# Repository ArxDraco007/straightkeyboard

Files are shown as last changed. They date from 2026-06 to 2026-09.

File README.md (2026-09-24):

# ArxKeyboard - A Custom Keyboard
## Building a custom mechanical keyboard from scratch.

## Why did I make this project?
Keyboards are a crucial part and parcel of your everyday life and efficiency, and it is crucial for you to have the very best.
It is also a very fun project to make, and it is also very cool to have your own custom keyboard.

## Description
This keyboard is a full-size mechanical keyboard. This has a custom PCB built around an ESP32-S3 WROOM. It contains a 6x17 switch matrix. It is a  two-piece case, red top shell over a blue base, designed in Fusion 360 and printed to match hole-for-hole with the PCB mounting points. It is running KMK on the firmware side.

## Pictures - 
The Schematic


The PCB


The CAD Model
keeb

## Zine
zine (7)

# Bill of Materials (BOM)

| Ref. | Value / Part Number | Footprint | Qty. | Supplier | Link | Notes |
|:---|:---|:---|---:|:---|:---|:---|
| C1 | 100 nF | 0603 | 1 | Robu.in | [100 nF 0603 — Pack of 40](https://robu.in/product/100nf-0603-surface-mount-multilayer-ceramic-capacitor-pack-of-40) | X7R, 50 V |
| C2 | 22 nF | 0603 | 1 | Robu.in | [22 nF 0603 — Pack of 50](https://robu.in/product/22nf-0603-surface-mount-multilayer-ceramic-capacitor-pack-of-50/) | 0603 MLCC |
| C11 | 10 µF | EIA-3216-18 (Case A) | 1 | Robu.in | [Vishay 10 µF 16 V Tantalum](https://robu.in/product/293d106x0016a2te3-vishay-tantalum-capacitor-10uf-16v-3-ohm-0-2-3216-18) | Vishay, 10 µF, 16 V; check stock |
| C12 | 22 µF | EIA-3216-18 (Case A) | 1 | element14 India | [22 µF 3216 Tantalum](https://in.element14.com/search?st=22uF+3216+tantalum) | Source from element14 India |
| R1 | 5.1 kΩ | 0603 | 1 | Robu.in | [YAGEO RC0603JR-075K1L](https://robu.in/product/rc0603jr-075k1l-yageo-res-thick-film-0603-5-1k-ohm-5-0-1w1-10w-%C2%B1100ppm-c-pad-smd-t-r/) | USB-C CC pull-down |
| R2 | 5.1 kΩ | 0603 | 1 | Robu.in | [YAGEO RC0603JR-075K1L](https://robu.in/product/rc0603jr-075k1l-yageo-res-thick-film-0603-5-1k-ohm-5-0-1w1-10w-%C2%B1100ppm-c-pad-smd-t-r/) | USB-C CC pull-down |
| R4 | 10 kΩ | 0603 | 1 | Robu.in | [10 kΩ 0603 SMD — Pack of 100](https://robu.in/product/10k-ohm-1-4w-0603-surface-mount-chip-resistor-pack-of-100/) | 1/4 W SMD resistor |
| D1–D88 | 1N4148W-7-F | SOD-123 | 88 | Evelta.com | [1N4148W-7-F — Diodes Inc.](https://evelta.com/1n4148w-7-f-100v-300ma-fast-switching-diode-2pin-smt-sod123/) | 100 V, 300 mA; genuine Diodes Inc. |
| U1 | ESP32-S3-WROOM-1-N16R8 | Module | 1 | Robu.in | [ESP32-S3-WROOM-1-N16R8](https://robu.in/product/espressif-esp32-s3-wroom-1-n16r8-module/) | 16 MB Flash, 8 MB PSRAM |
| U2 | AMS1117-3.3 | SOT-223 | 1 | Evelta.com | [AMS1117-3.3](https://evelta.com/ams1117-3-3-advanced-monolithic-systems-3-3v-1a-ldo-voltage-regulator/) | 3.3 V, 1 A LDO |
| J1 | GCT USB4105-GF-A-060 | 16P Top-Mount SMD | 1 | element14 India | [USB4105-GF-A-060](https://in.element14.com/gct-global-connector-technology/usb4105-gf-a-060/usb-conn-2-0-type-c-r-a-rcpt-16pos/dp/3777659) | USB-C, 16-pin, top-mount SMD |
| SW1–SW88 | Cherry MX2A | PCB Mount | 88 | Meckeys.com | [Cherry MX2A — 10 Pack](https://meckeys.com/shop/accessories/keyboard-accessories/key-switches/cherry-mx2a-switch/) | ₹350 / 10-pack; ≈ ₹3,080 total |
| PCB | ArxKey, 2-Layer, 280 × 130 mm | — | 5 | JLCPCB | [JLCPCB](https://jlcpcb.com/) | Manufacturing cost: $7 |

---

## Cost Summary

| Item | Estimated Cost |
|:---|---:|
| Components | Included above |
| Cherry MX2A switches | ≈ ₹3,080 |
| PCB manufacturing — 5 boards | $7 |
| **Estimated Total** | **≈ $57** |

## Stuff You Need to Remember When Making This!!! - 
- The Case is of 5 parts, you just have to place them right and screw them properly.
- Make sure U1 is in the keepout zone.
- Flash the ESP32 before assembly for testing.
- Don't reverse Tantalum capacitors, they pop (Electroboom reference(if you get it)).
- One SOD-123 per key in the matrix facing right.
- Mount in mounting holes!
- Look at the zine and sandwich the PCB.
- Do everything right or else you're cooked.

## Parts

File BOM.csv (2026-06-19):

Ref | Value | Footprint | Qty | Supplier | Link | Notes
C1 | 100nF | 0603 | 1 | Robu.in | https://robu.in/product/100nf-0603-surface-mount-multilayer-ceramic-capacitor-pack-of-40 | X7R 50V
C2 | 22nF | 0603 | 1 | Robu.in | https://robu.in/product/22nf-0603-surface-mount-multilayer-ceramic-capacitor-pack-of-50/ | 0603 MLCC
C11 | 10uF | EIA-3216-18 (Case A) | 1 | Robu.in | https://robu.in/product/293d106x0016a2te3-vishay-tantalum-capacitor-10uf-16v-3-ohm-0-2-3216-18 | Vishay 10uF 16V Tantalum; check stock
C12 | 22uF | EIA-3216-18 (Case A) | 1 | element14 India | https://in.element14.com/search?st=22uF+3216+tantalum | No confirmed listing on Robu/Evelta; source from element14 India
R1 | 5.1kΩ | 0603 | 1 | Robu.in | https://robu.in/product/rc0603jr-075k1l-yageo-res-thick-film-0603-5-1k-ohm-5-0-1w1-10w-%C2%B1100ppm-c-pad-smd-t-r/ | USB-C CC pull-down; YAGEO RC0603JR-075K1L
R2 | 5.1kΩ | 0603 | 1 | Robu.in | https://robu.in/product/rc0603jr-075k1l-yageo-res-thick-film-0603-5-1k-ohm-5-0-1w1-10w-%C2%B1100ppm-c-pad-smd-t-r/ | USB-C CC pull-down; YAGEO RC0603JR-075K1L
R4 | 10kΩ | 0603 | 1 | Robu.in | https://robu.in/product/10k-ohm-1-4w-0603-surface-mount-chip-resistor-pack-of-100/ | 10k 1/4W 0603 SMD
D1-D88 | 1N4148W-7-F | SOD-123 | 88 | Evelta.com | https://evelta.com/1n4148w-7-f-100v-300ma-fast-switching-diode-2pin-smt-sod123/ | Diodes Inc; 100V 300mA; genuine
U1 | ESP32-S3-WROOM-1-N16R8 | Module | 1 | Robu.in | https://robu.in/product/espressif-esp32-s3-wroom-1-n16r8-module/ | 16MB Flash 8MB PSRAM
U2 | AMS1117-3.3 | SOT-223 | 1 | Evelta.com | https://evelta.com/ams1117-3-3-advanced-monolithic-systems-3-3v-1a-ldo-voltage-regulator/ | AMS original; 1A LDO; ~₹12
J1 | GCT USB4105-GF-A | 16P Top Mount SMD | 1 | element14 India | https://in.element14.com/gct-global-connector-technology/usb4105-gf-a-060/usb-conn-2-0-type-c-r-a-rcpt-16pos/dp/3777659 | USB-C 16P top mount SMD
SW1-SW88 | Cherry MX2A | PCB Mount | 88 | Meckeys.com | https://meckeys.com/shop/accessories/keyboard-accessories/key-switches/cherry-mx2a-switch/ | ₹3080 total
PCB | ArxKey 2-layer | 280x130mm | qty 5*1 | JLCPCB | jlcpcb.com | $7 Manufacturing PCB
Total |  |  |  |  |  | $57

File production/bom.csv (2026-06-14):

Designator | Footprint | Quantity | Value | LCSC Part #
C1 | 0603 | 1 | 100nF
C11 | CP_EIA-3216-18_Kemet-A | 1 | 10uF
C12 | CP_EIA-3216-18_Kemet-A | 1 | 22uF
C2 | 0603 | 1 | 22nF
D1, D10, D11, D12, D13, D14, D15, D16, D17, D18, D19, D2, D20, D21, D22, D23, D24, D25, D26, D27, D28, D29, D3, D30, D31, D32, D33, D34, D35, D36, D37, D38, D39, D4, D40, D41, D42, D43, D44, D45, D46, D47, D48, D49, D5, D50, D51, D52, D53, D54, D55, D56, D57, D58, D59, D6, D60, D61, D62, D63, D64, D65, D66, D67, D68, D69, D7, D70, D71, D72, D73, D74, D75, D76, D77, D78, D79, D8, D80, D81, D82, D83, D84, D85, D86, D87, D88, D9 | D_SOD-123 | 88 | ~
J1 | USB_C_Receptacle_GCT_USB4105-xx-A_16P_TopMnt_Horizontal | 1 | USB_C_Receptacle_USB2.0_16P
R1, R2 | 0603 | 2 | 5.1k
R4 | 0603 | 1 | 10k
S1, S10, S11, S12, S13, S14, S15, S16, S17, S18, S19, S2, S20, S21, S22, S23, S24, S25, S26, S27, S28, S29, S3, S31, S32, S33, S35, S36, S37, S38, S39, S4, S40, S41, S42, S43, S44, S45, S46, S48, S49, S5, S50, S52, S53, S54, S55, S56, S57, S58, S59, S6, S60, S61, S62, S63, S65, S66, S67, S68, S69, S7, S70, S71, S72, S73, S74, S75, S77, S79, S8, S80, S82, S83, S84, S86, S87, S88, S9 | SW_Cherry_MX_1.00u_PCB | 79 | ~
S30 | SW_Cherry_MX_2.00u_PCB | 1 | ~
S34 | SW_Cherry_MX_1.50u_PCB | 1 | ~
S47 | SW_Cherry_MX_ISOEnter_PCB | 1 | ~
S51 | SW_Cherry_MX_1.75u_PCB | 1 | ~
S64, S78, S85 | SW_Cherry_MX_1.25u_PCB | 3 | ~
S76 | SW_Cherry_MX_2.75u_PCB | 1 | ~
S81 | SW_Cherry_MX_6.25u_PCB | 1 | ~
U1 | ESP32-S3-WROOM-1 | 1 | ESP32-S3-WROOM-1
U2 | SOT-223-3_TabPin2 | 1 | AMS1117-3.3

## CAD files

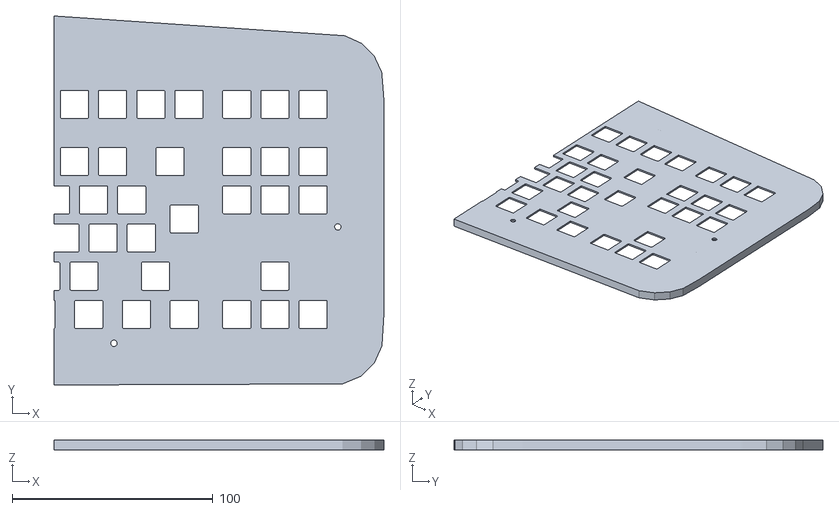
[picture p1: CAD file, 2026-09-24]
CAD/Top-right.stl
164.3 x 184.0 x 5.04

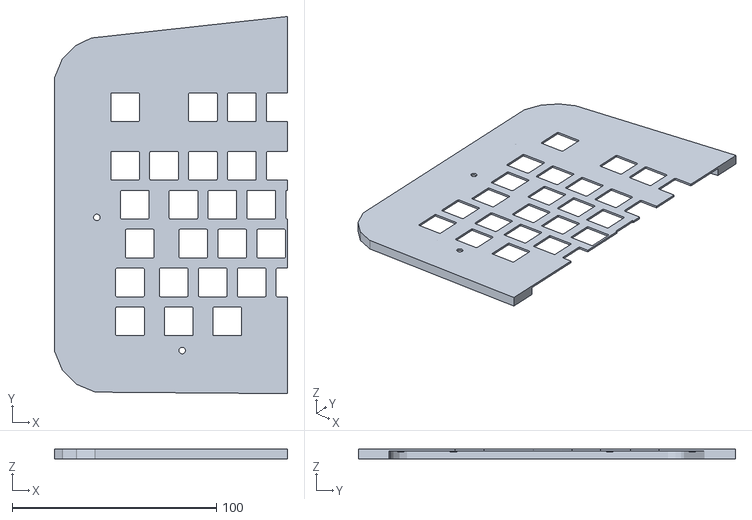
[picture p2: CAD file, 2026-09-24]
CAD/Top-left.stl
114.0 x 184.5 x 5.04

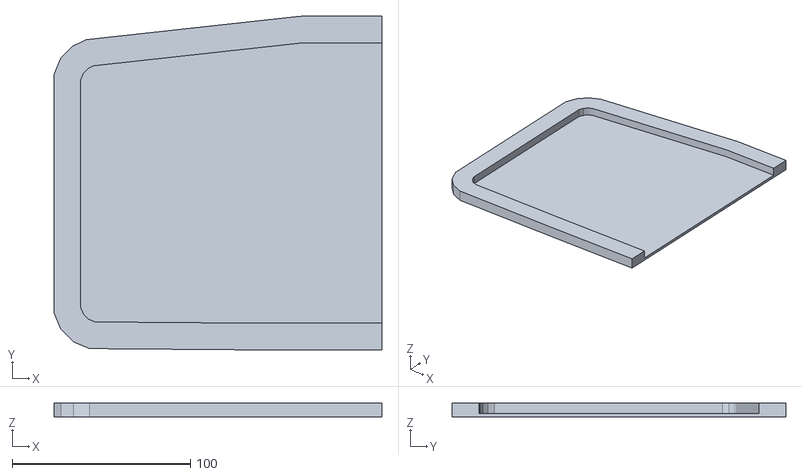
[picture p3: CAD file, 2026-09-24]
CAD/bottom-left.stl
184.0 x 187.2 x 8.00

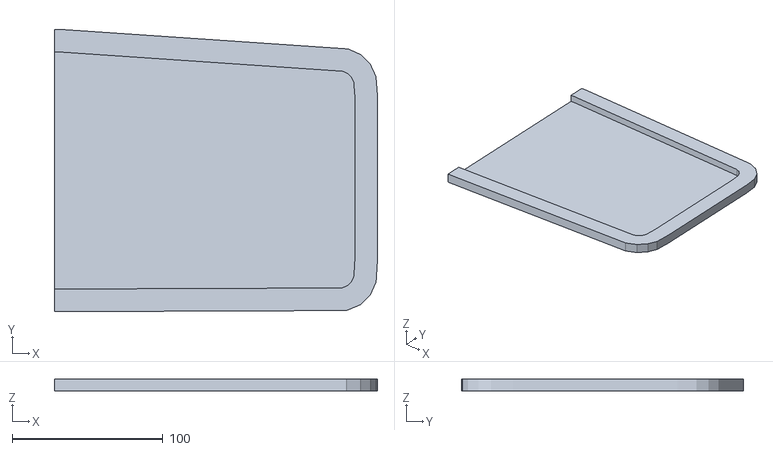
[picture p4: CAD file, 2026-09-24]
CAD/bottom-right.stl
214.3 x 187.2 x 8.00

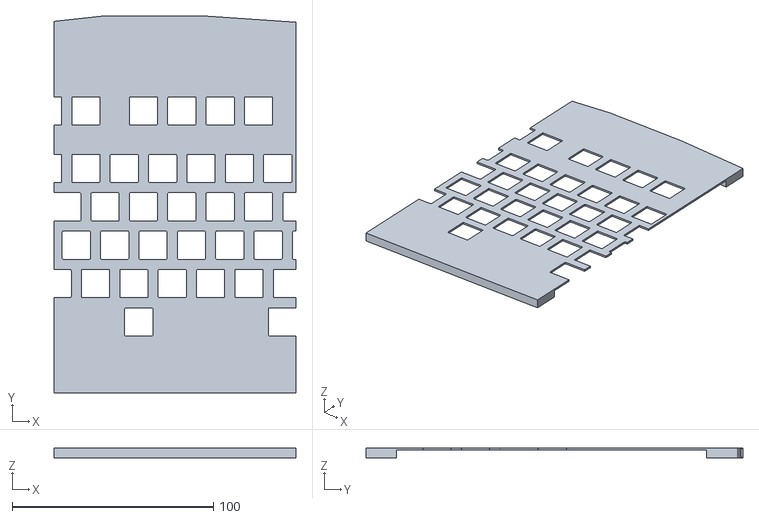
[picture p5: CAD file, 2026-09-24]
CAD/Top-middle.stl
120.0 x 187.2 x 5.04

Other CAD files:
CAD/Assembly.f3z

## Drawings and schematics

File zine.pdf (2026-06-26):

# ARX KEYBOARD

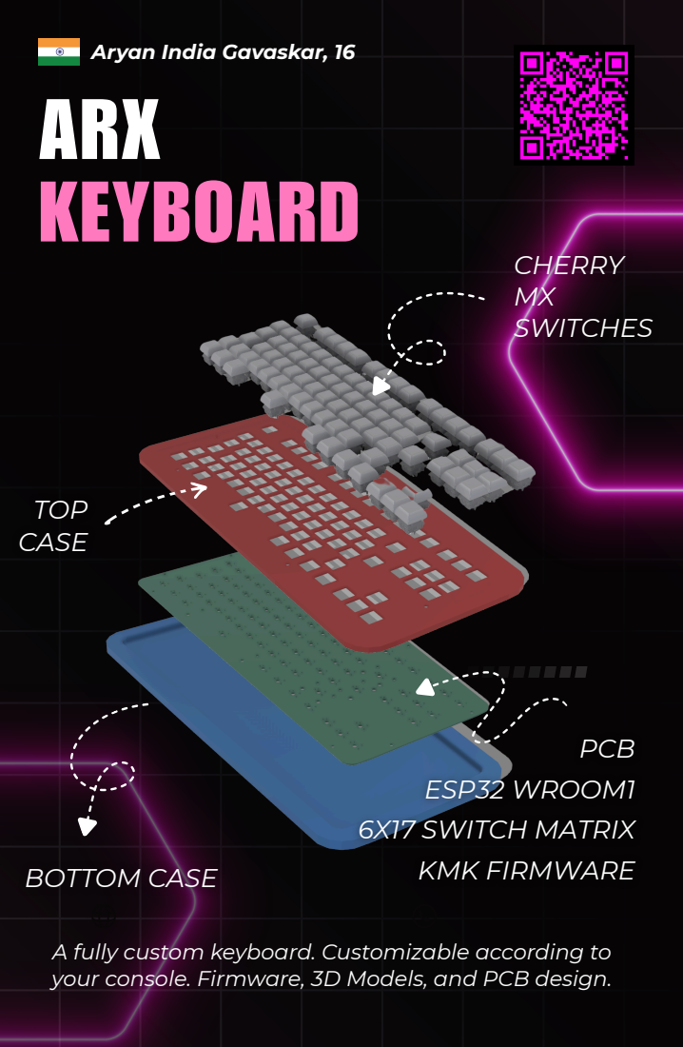
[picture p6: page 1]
BOTTOM CASE; CHERRY MX SWITCHES; TOP CASE; PCB ESP32 WROOM1 6X17 SWITCH MATRIX KMK FIRMWARE

Aryan India Gavaskar, 16

A fully custom keyboard. Customizable according to
your console. Firmware, 3D Models, and PCB design.

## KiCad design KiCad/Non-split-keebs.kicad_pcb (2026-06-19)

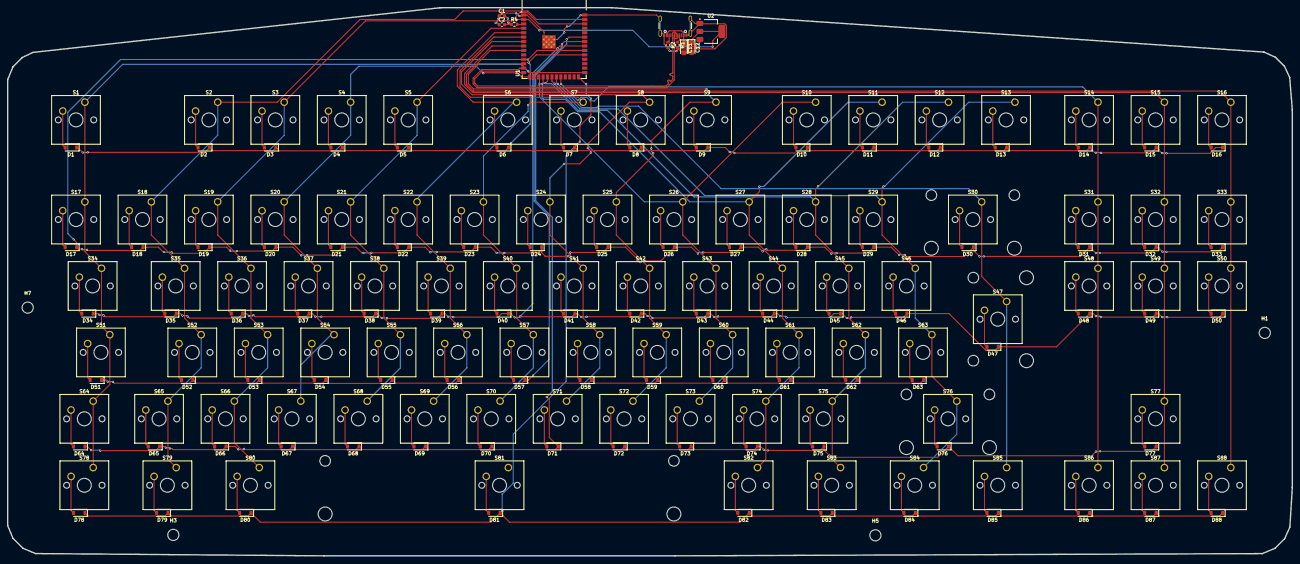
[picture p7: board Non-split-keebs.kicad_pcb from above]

Board: 2 copper layers, 368.4 x 157.2 mm, 190 parts (0 on the bottom side), 119 nets.

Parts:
C1: 100nF; C_0603_1608Metric
C2: 22nF; C_0603_1608Metric
C11: 10uF; CP_EIA-3216-18_Kemet-A
C12: 22uF; CP_EIA-3216-18_Kemet-A
D1, D2, D3, D4, D5, D6, D7, D8, D9, D10, D11, D12, D13, D14, D15, D16, D17, D18, D19, D20, D21, D22, D23, D24, D25, D26, D27, D28, D29, D30, D31, D32, D33, D34, D35, D36, D37, D38, D39, D40, D41, D42, D43, D44, D45, D46, D47, D48, D49, D50, D51, D52, D53, D54, D55, D56, D57, D58, D59, D60, D61, D62, D63, D64, D65, D66, D67, D68, D69, D70, D71, D72, D73, D74, D75, D76, D77, D78, D79, D80, D81, D82, D83, D84, D85, D86, D87, D88: D_SOD-123
H1, H3, H5, H7: MountingHole; MountingHole_3.2mm_M3
J1: USB_C_Receptacle_USB2.0_16P; USB_C_Receptacle_GCT_USB4105-xx-A_16P_TopMnt_Horizontal
R1, R2: 5.1k; R_0603_1608Metric
R4: 10k; R_0603_1608Metric
S1, S2, S3, S4, S5, S6, S7, S8, S9, S10, S11, S12, S13, S14, S15, S16, S17, S18, S19, S20, S21, S22, S23, S24, S25, S26, S27, S28, S29, S31, S32, S33, S35, S36, S37, S38, S39, S40, S41, S42, S43, S44, S45, S46, S48, S49, S50, S52, S53, S54, S55, S56, S57, S58, S59, S60, S61, S62, S63, S65, S66, S67, S68, S69, S70, S71, S72, S73, S74, S75, S77, S79, S80, S82, S83, S84, S86, S87, S88: SW_Cherry_MX_1.00u_PCB
S30: SW_Cherry_MX_2.00u_PCB
S34: SW_Cherry_MX_1.50u_PCB
S47: SW_Cherry_MX_ISOEnter_PCB
S51: SW_Cherry_MX_1.75u_PCB
S64, S78, S85: SW_Cherry_MX_1.25u_PCB
S76: SW_Cherry_MX_2.75u_PCB
S81: SW_Cherry_MX_6.25u_PCB
U1: ESP32-S3-WROOM-1
U2: AMS1117-3.3; SOT-223-3_TabPin2

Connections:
+3V3: C1.2, C2.2, C12.1, R4.1, U1.2 (3V3), U2.2 (VO)
+5V: C11.1, J1.A4 (VBUS), J1.A9 (VBUS), J1.B4 (VBUS), J1.B9 (VBUS), U2.3 (VI)
COL0: S1.1, S17.1, S34.1, S51.1, S64.1, S78.1, U1.27 (IO0)
COL1: S2.1, S18.1, S35.1, S52.1, S65.1, S79.1, U1.39 (IO1)
COL2: S3.1, S19.1, S36.1, S53.1, S66.1, S80.1, U1.38 (IO2)
COL3: S4.1, S20.1, S37.1, S54.1, S67.1, U1.15 (IO3)
COL4: S5.1, S21.1, S38.1, S55.1, S68.1, U1.4 (IO4)
COL5: S6.1, S22.1, S39.1, S56.1, S69.1, U1.5 (IO5)
COL6: S7.1, S23.1, S40.1, S57.1, S70.1, U1.6 (IO6)
COL7: S8.1, S24.1, S41.1, S58.1, S71.1, U1.7 (IO7)
COL8: S9.1, S25.1, S42.1, S59.1, S72.1, U1.12 (IO8)
COL9: S10.1, S26.1, S43.1, S60.1, S73.1, U1.17 (IO9)
COL10: S11.1, S27.1, S44.1, S61.1, S74.1, S82.1, U1.18 (IO10)
COL11: S12.1, S28.1, S45.1, S62.1, S75.1, S83.1, U1.19 (IO11)
COL12: S13.1, S29.1, S46.1, S63.1, S76.1, S84.1, U1.20 (IO12)
COL13: S30.1, S47.1, S85.1, U1.21 (IO13)
COL14: S14.1, S31.1, S48.1, S86.1, U1.22 (IO14)
COL15: S15.1, S32.1, S49.1, S77.1, S87.1, U1.8 (IO15)
COL16: S16.1, S33.1, S50.1, S88.1, U1.9 (IO16)
D+: J1.A6 (D+), J1.B6 (D+), U1.14 (USB_D+)
D-: J1.A7 (D-), J1.B7 (D-), U1.13 (USB_D-)
GND: C1.1, C2.1, C11.2, C12.2, J1.A1 (GND), J1.A12 (GND), J1.B1 (GND), J1.B12 (GND), J1.SH (SHIELD), R1.2, R2.2, U1.1 (GND), U1.40 (GND), U1.41 (GND), U2.1 (GND)
unnamed: D1.2 (A), S1.2
unnamed: D2.2 (A), S2.2
unnamed: D3.2 (A), S3.2
unnamed: D4.2 (A), S4.2
unnamed: D5.2 (A), S5.2
unnamed: D6.2 (A), S6.2
unnamed: D7.2 (A), S7.2
unnamed: D8.2 (A), S8.2
unnamed: D9.2 (A), S9.2
unnamed: D10.2 (A), S10.2
unnamed: D11.2 (A), S11.2
unnamed: D12.2 (A), S12.2
unnamed: D13.2 (A), S13.2
unnamed: D14.2 (A), S14.2
unnamed: D15.2 (A), S15.2
unnamed: D16.2 (A), S16.2
unnamed: D17.2 (A), S17.2
unnamed: D18.2 (A), S18.2
unnamed: D19.2 (A), S19.2
unnamed: D20.2 (A), S20.2
unnamed: D21.2 (A), S21.2
unnamed: D22.2 (A), S22.2
unnamed: D23.2 (A), S23.2
unnamed: D24.2 (A), S24.2
unnamed: D25.2 (A), S25.2
unnamed: D26.2 (A), S26.2
unnamed: D27.2 (A), S27.2
unnamed: D28.2 (A), S28.2
unnamed: D29.2 (A), S29.2
unnamed: D30.2 (A), S30.2
unnamed: D31.2 (A), S31.2
unnamed: D32.2 (A), S32.2
unnamed: D33.2 (A), S33.2
unnamed: D34.2 (A), S34.2
unnamed: D35.2 (A), S35.2
unnamed: D36.2 (A), S36.2
unnamed: D37.2 (A), S37.2
unnamed: D38.2 (A), S38.2
unnamed: D39.2 (A), S39.2
unnamed: D40.2 (A), S40.2
unnamed: D41.2 (A), S41.2
unnamed: D42.2 (A), S42.2
unnamed: D43.2 (A), S43.2
unnamed: D44.2 (A), S44.2
unnamed: D45.2 (A), S45.2
unnamed: D46.2 (A), S46.2
unnamed: D47.2 (A), S47.2
unnamed: D48.2 (A), S48.2
unnamed: D49.2 (A), S49.2
unnamed: D50.2 (A), S50.2
unnamed: D51.2 (A), S51.2
unnamed: D52.2 (A), S52.2
unnamed: D53.2 (A), S53.2
unnamed: D54.2 (A), S54.2
unnamed: D55.2 (A), S55.2
unnamed: D56.2 (A), S56.2
unnamed: D57.2 (A), S57.2
unnamed: D58.2 (A), S58.2
unnamed: D59.2 (A), S59.2
unnamed: D60.2 (A), S60.2
unnamed: D61.2 (A), S61.2
unnamed: D62.2 (A), S62.2
unnamed: D63.2 (A), S63.2
unnamed: D64.2 (A), S64.2
unnamed: D65.2 (A), S65.2
unnamed: D66.2 (A), S66.2
unnamed: D67.2 (A), S67.2
unnamed: D68.2 (A), S68.2
unnamed: D69.2 (A), S69.2
unnamed: D70.2 (A), S70.2
unnamed: D71.2 (A), S71.2
unnamed: D72.2 (A), S72.2
unnamed: D73.2 (A), S73.2
unnamed: D74.2 (A), S74.2
unnamed: D75.2 (A), S75.2
unnamed: D76.2 (A), S76.2
unnamed: D77.2 (A), S77.2
unnamed: D78.2 (A), S78.2
unnamed: D79.2 (A), S79.2
unnamed: D80.2 (A), S80.2
unnamed: D81.2 (A), S81.2 (2_2)
unnamed: D82.2 (A), S82.2
unnamed: D83.2 (A), S83.2
unnamed: D84.2 (A), S84.2
unnamed: D85.2 (A), S85.2
unnamed: D86.2 (A), S86.2
unnamed: D87.2 (A), S87.2
unnamed: D88.2 (A), S88.2
unnamed: J1.A5 (CC1), R1.1
unnamed: J1.B5 (CC2), R2.1
unnamed: R4.2, U1.3 (EN)
ROW0: D1.1 (K), D2.1 (K), D3.1 (K), D4.1 (K), D5.1 (K), D6.1 (K), D7.1 (K), D8.1 (K), D9.1 (K), D10.1 (K), D11.1 (K), D12.1 (K), D13.1 (K), D14.1 (K), D15.1 (K), D16.1 (K), U1.31 (IO38)
ROW1: D17.1 (K), D18.1 (K), D19.1 (K), D20.1 (K), D21.1 (K), D22.1 (K), D23.1 (K), D24.1 (K), D25.1 (K), D26.1 (K), D27.1 (K), D28.1 (K), D29.1 (K), D30.1 (K), D31.1 (K), D32.1 (K), D33.1 (K), U1.32 (IO39)
ROW2: D34.1 (K), D35.1 (K), D36.1 (K), D37.1 (K), D38.1 (K), D39.1 (K), D40.1 (K), D41.1 (K), D42.1 (K), D43.1 (K), D44.1 (K), D45.1 (K), D46.1 (K), D47.1 (K), D48.1 (K), D49.1 (K), D50.1 (K), U1.33 (IO40)
ROW3: D51.1 (K), D52.1 (K), D53.1 (K), D54.1 (K), D55.1 (K), D56.1 (K), D57.1 (K), D58.1 (K), D59.1 (K), D60.1 (K), D61.1 (K), D62.1 (K), D63.1 (K), U1.34 (IO41)
ROW4: D64.1 (K), D65.1 (K), D66.1 (K), D67.1 (K), D68.1 (K), D69.1 (K), D70.1 (K), D71.1 (K), D72.1 (K), D73.1 (K), D74.1 (K), D75.1 (K), D76.1 (K), D77.1 (K), U1.35 (IO42)
ROW5: D78.1 (K), D79.1 (K), D80.1 (K), D81.1 (K), D82.1 (K), D83.1 (K), D84.1 (K), D85.1 (K), D86.1 (K), D87.1 (K), D88.1 (K), U1.26 (IO45)

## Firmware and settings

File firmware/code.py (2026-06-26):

import board
from kmk.kmk_keyboard import KMKKeyboard
from kmk.scanners.keypad import MatrixScanner
from kmk.modules.holdtap import HoldTap
from kmk.modules.layers import Layers

keyboard = KMKKeyboard()
COL_PINS = (board.IO0,  board.IO1,  board.IO2,  board.IO3, board.IO4,  board.IO5,  board.IO6,  board.IO7,
board.IO8,  board.IO9,  board.IO10, board.IO11, board.IO12, board.IO13, board.IO14, board.IO15,
board.IO16,)
ROW_PINS = (board.IO38, board.IO39, board.IO40, board.IO42, board.IO45, board.IO48,)
keyboard.matrix = MatrixScanner(column_pins=COL_PINS,row_pins=ROW_PINS,columns_to_anodes=True,)
keyboard.modules.append(Layers())
keyboard.modules.append(HoldTap())
from kmk.keys import KC

keyboard.keymap = [[
        KC.ESC,  KC.F1,   KC.F2,   KC.F3,   KC.F4,   KC.F5,   KC.F6,   KC.F7,
        KC.F8,   KC.F9,   KC.F10,  KC.F11,  KC.F12,  KC.PSCR, KC.SLCK, KC.PAUS, KC.NO,
        KC.GRV,  KC.N1,   KC.N2,   KC.N3,   KC.N4,   KC.N5,   KC.N6,   KC.N7,
        KC.N8,   KC.N9,   KC.N0,   KC.MINS, KC.EQL,  KC.BSPC, KC.INS,  KC.HOME, KC.PGUP,
        KC.TAB,  KC.Q,    KC.W,    KC.E,    KC.R,    KC.T,    KC.Y,    KC.U,
        KC.I,    KC.O,    KC.P,    KC.LBRC, KC.RBRC, KC.ENT,  KC.DEL,  KC.END,  KC.PGDN,
        KC.CAPS, KC.A,    KC.S,    KC.D,    KC.F,    KC.G,    KC.H,    KC.J,
        KC.K,    KC.L,    KC.SCLN, KC.QUOT, KC.NUHS, KC.NO,   KC.NO,   KC.NO,   KC.NO,
        KC.LSFT, KC.NUBS, KC.Z,    KC.X,    KC.C,    KC.V,    KC.B,    KC.N,
        KC.M,    KC.COMM, KC.DOT,  KC.SLSH, KC.RSFT, KC.NO,   KC.NO,   KC.UP,   KC.NO,
        KC.LCTL, KC.LGUI, KC.LALT, KC.SPC,  KC.NO,   KC.NO,   KC.NO,   KC.NO,
        KC.RALT, KC.RGUI, KC.APP,  KC.RCTL, KC.NO,   KC.NO,   KC.LEFT, KC.DOWN, KC.RGHT,
    ],]

if __name__ == '__main__':
    keyboard.go()

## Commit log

2026-06-14 prod files
    [Non-split-keebs.kicad_pcb, Non-split-keebs.kicad_sch, bom.csv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]
2026-06-14 pcb and prod
    [Non-split-keebs.kicad_pcb, Non-split-keebs.kicad_sch, bom.csv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]
2026-06-14 BOM and Assembly files
    [BOM.csv, top.step]
2026-06-16 prod and pcb files
2026-06-16 updated cad files
    [bottom.step, top.step]
2026-06-19 pcb files changes
    [Non-split-keebs.kicad_pcb, Non-split-keebs.kicad_sch, designators.csv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]
2026-09-24 Add Bill of Materials and cost summary to README
    Added a Bill of Materials (BOM) section with detailed component information and a cost summary.
2026-09-24 CAD files
    [Assembly.f3z, Top-left.stl, Top-middle.stl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]
2026-09-24 Update README with assembly instructions
    Added important assembly notes and reminders.
